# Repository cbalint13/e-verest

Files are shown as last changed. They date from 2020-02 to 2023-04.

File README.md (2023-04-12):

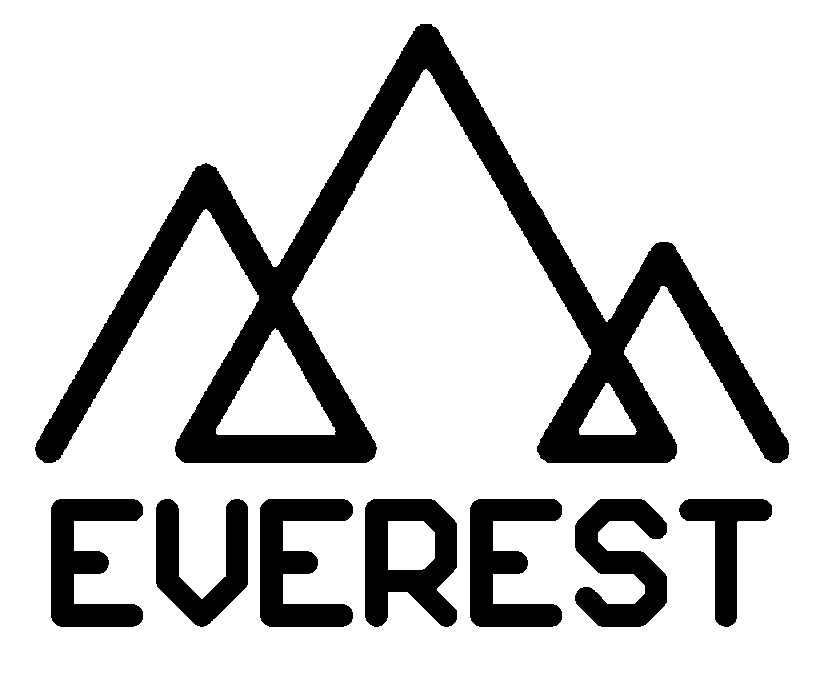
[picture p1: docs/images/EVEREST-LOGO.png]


**e**-**Ve**rsatile **Re**search **St**ick for peoples

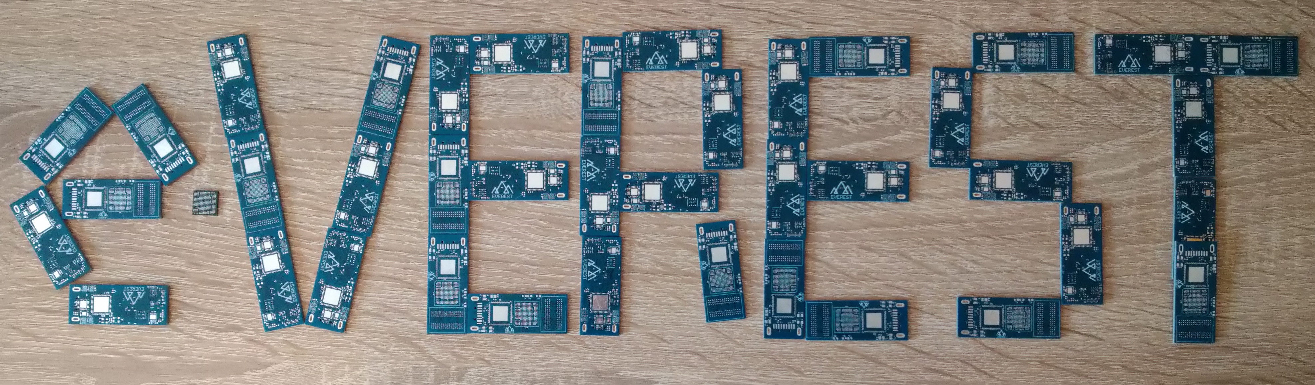
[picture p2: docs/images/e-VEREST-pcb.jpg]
PCB

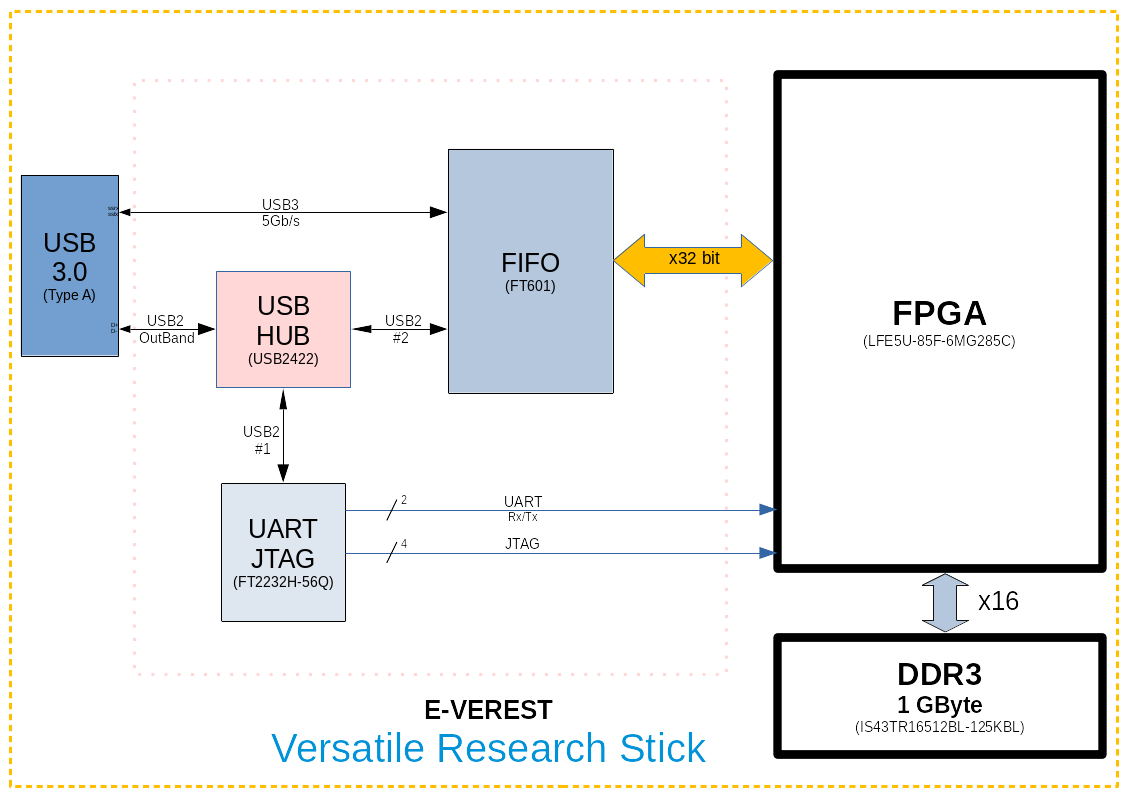
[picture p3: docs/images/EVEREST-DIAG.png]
DIAG


## Description

  With the rising of high quality opensource tools for FPGAs new opportunities are emerging to discover and build better digital architectures.
  This stick is intended as lowest cost tool for anyone who desire to explore & research the world of modern digital systems.
  It can be used to develop, test and benchmark fairly large digital designs, straight using a complete opensource toolchain end to end.

  It can close the gap between emerging trend of high level generated systems (automatic reinforced exploration of arhitectures) and the lack of end to end toolchain harvesting a real FPGA for final feedback.

  Let Here Be Dragons !

## Specs:

* Small size **16x40mm** usb stick
* Generous **85k LUT** **FPGA** logic space
* Holds **1Gbyte DDR3** memory with **x16** wide access
* USB3 **5Gbps/s** data access over **x32** wide independent FIFO
* USB2 outband (same usb port) permanent **JTAG** and **UART** independent access
* Full opensource HDL flow usig [YoSYS](https://github.com/YosysHQ) suite

Can be used in any USB port right from the tips of fingers, no cables, no wires but full control.

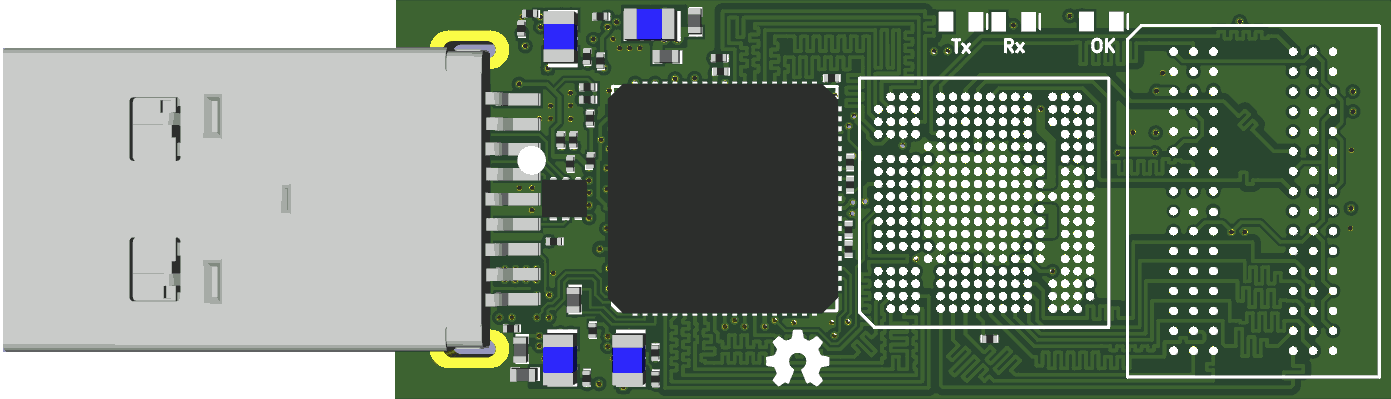
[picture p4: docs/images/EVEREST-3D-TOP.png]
OVERVIEW-TOP

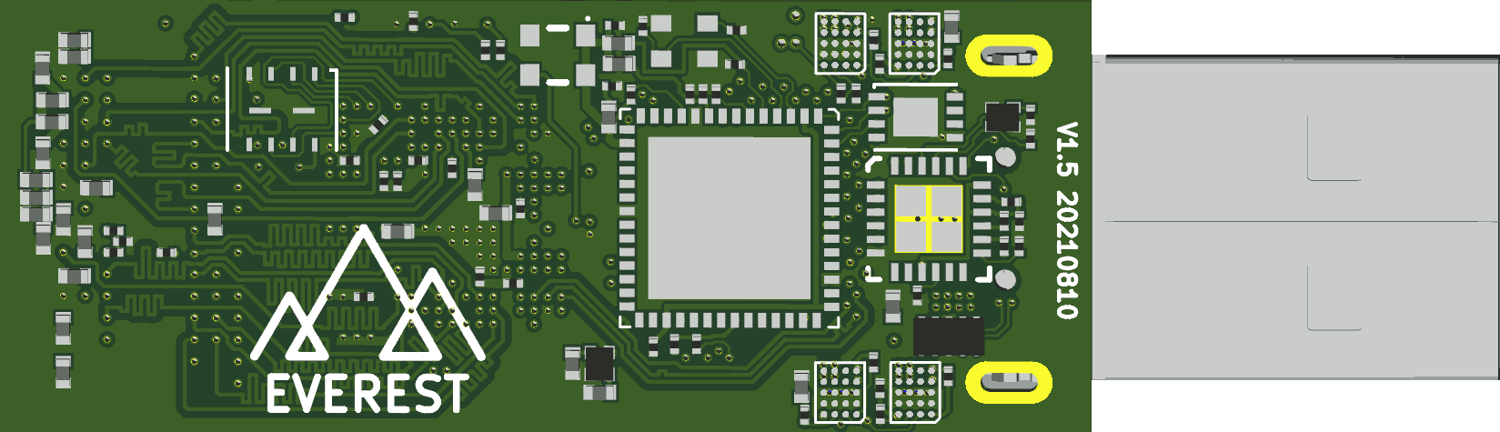
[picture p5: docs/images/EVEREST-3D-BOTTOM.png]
OVERVIEW-BOTTOM


## Progress:
* ```23-Apr-2020``` A batch of 50 PCB arrived. Thank you [WellPCB PTY LTD](https://www.wellpcb.com) !
* ```20-Dec-2020``` Second iteraton of PCB has been done, schematics and pcb design are updated.
* ```20-Jan-2021``` Announcing [OLIMP](https://github.com/cbalint13/OLIMP) having e-VEREST as demo board.
* ```17-Aug-2021``` Third iteration of PCB has been done, design is updated.
* ```10-May-2022``` Due to severe global shortage ~~crowd source~~ batches aren't possible until >2023.

```
Booting..
Press ENTER to continue..

     __     _______ ____  _____ ____ _____
   __\ \   / | ____|  _ \| ____/ ___|_   _|
  / _ \ \ / /|  _| | |_) |  _| \___ \ | |
 |  __/\ V / | |___|  _ <| |___ ___) || |
  \___| \_/  |_____|_| \_|_____|____/ |_|

Total BRAM memory: 32 KiB

Select an action:

   [e] Echo UART

Command>
```

See [utils](/utils) for board peripherial tests and [i/o mappings (lpf file)](https://github.com/cbalint13/e-verest/blob/master/utils/test-firmware/brd/everest.lpf).

## Project files
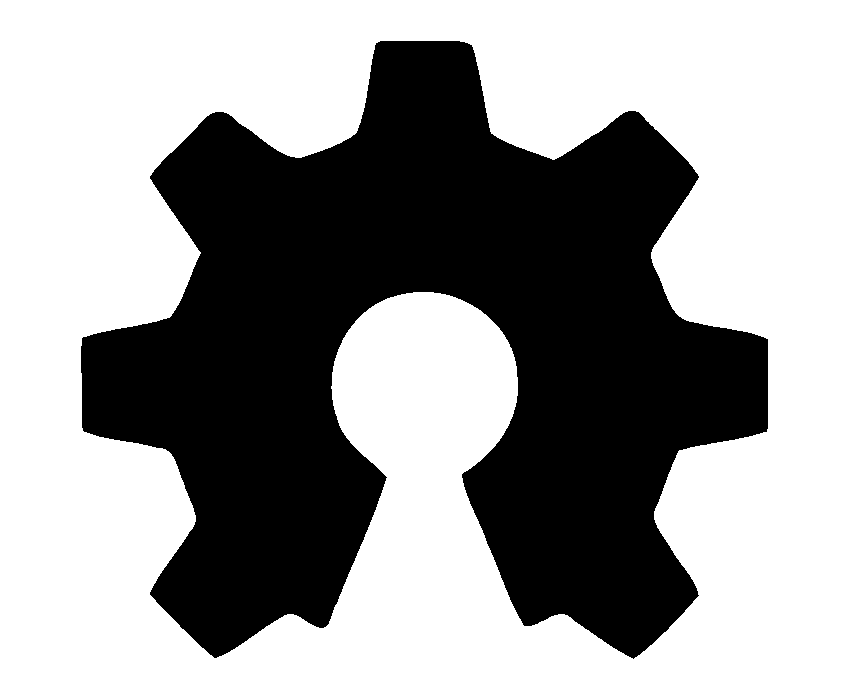
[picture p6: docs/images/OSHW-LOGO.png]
* Open Source Hardware 
* Check [schematic](hardware/e-VEREST-v1_5.pdf) available as quick readable document.
* See the [design files](hardware) available for Altium ®, CircuitMaker ®, KiCAD and Gerber format.
* There is also an CircuitMaker ® [online version](https://circuitmaker.com/Projects/Details/Cristian-Balint/e-VEREST) available.
* Software tools for managing the stick and examples coming soon (WiP)
* There are plans for making batch of units via CrowdSupply campains (WiP).

## PCB views

| Layer | Polygons Description |Image  |
| --- | --- |---|
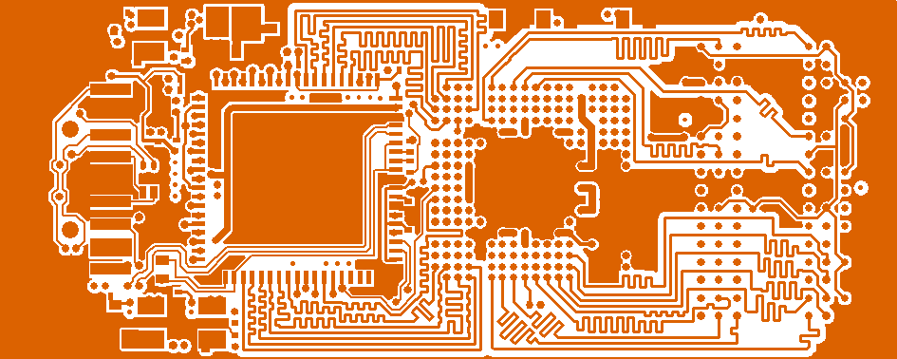
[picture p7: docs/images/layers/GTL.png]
Top Layer
| Top | Signal Layer | |
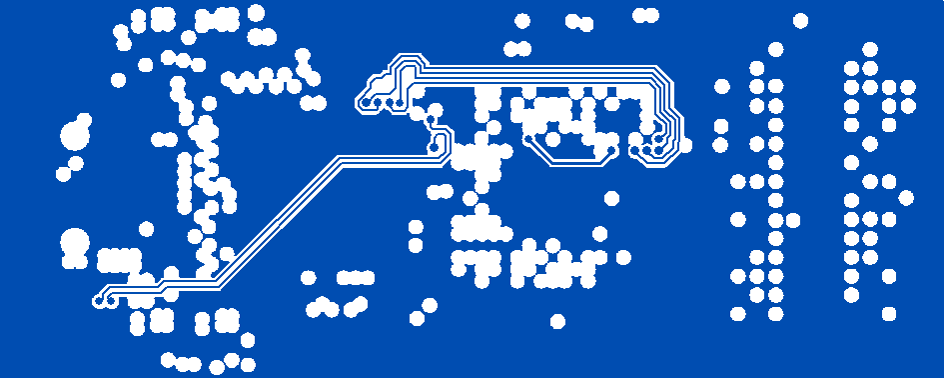
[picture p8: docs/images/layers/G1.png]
Inner Layer 1
| Inner 1 | GND Plane | |
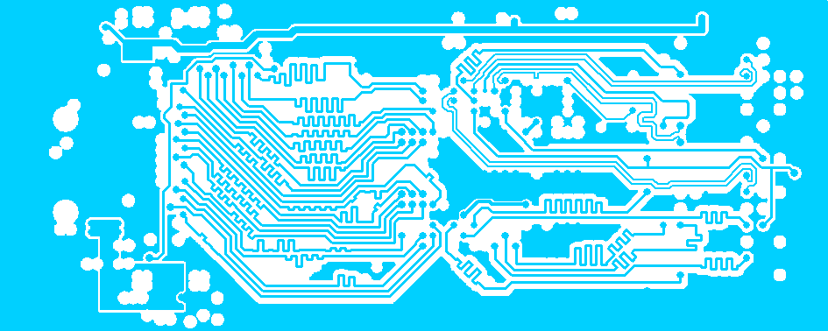
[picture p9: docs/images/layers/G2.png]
Inner Layer 2
| Inner 2 | Signal Layer | |
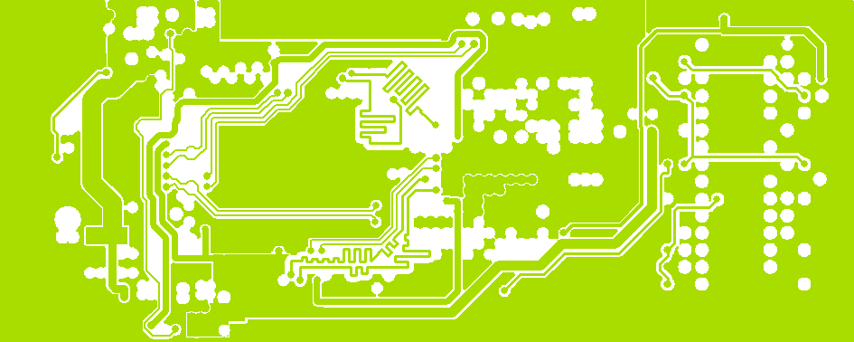
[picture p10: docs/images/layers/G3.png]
Inner Layer 3 Polygon
| Inner 3 | Power Plane | |
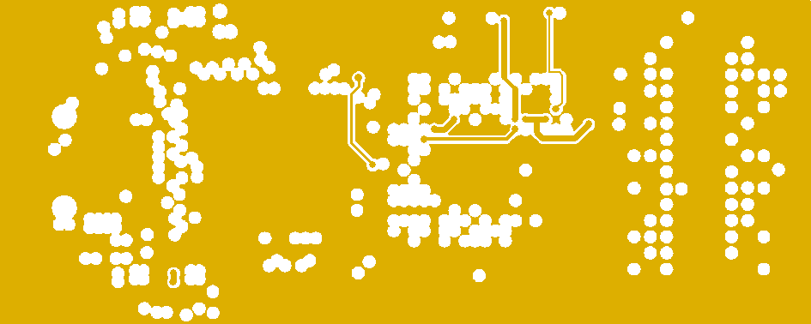
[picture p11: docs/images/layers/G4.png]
Inner Layer 4 Polygons
| Inner 4 | GND Plane | |
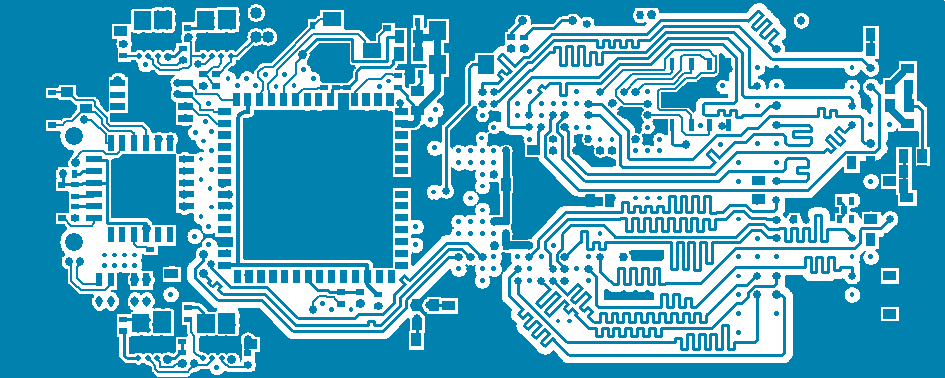
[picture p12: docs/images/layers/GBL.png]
Bottom Layer Polygon
| Bottom |  Signal Layer | |

## Credits

* Communities around [yosys](https://github.com/YosysHQ/yosys) / [nextpnr](https://github.com/YosysHQ/nextpnr)
* The [OrangeCrab](https://github.com/orangecrab-fpga/orangecrab-hardware) board design by Greg Davill

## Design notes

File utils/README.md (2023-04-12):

## USB

Two USB devices with 3 communication channels:
  * *FT2232* as high-speed with:
      - **JTAG** (port A) connected with FPGA
      - **UART** (port B) via /dev/ttyUSB1 to FPGA
  * *FT601* as super-speed x32 bit **FIFO** with the FPGA

```
$ lsusb
Bus 002 Device 002: ID 0403:601f Future Technology Devices International, Ltd FT601 32-bit FIFO IC
Bus 001 Device 012: ID 0403:6010 Future Technology Devices International, Ltd FT2232C/D/H Dual UART/FIFO IC

$ dmesg
[   50.046996] usb 1-6: new high-speed USB device number 7 using xhci_hcd
[   50.173128] usb 1-6: New USB device found, idVendor=0424, idProduct=2422, bcdDevice= 0.a0
[   50.173143] usb 1-6: New USB device strings: Mfr=0, Product=0, SerialNumber=0
[   50.175616] hub 1-6:1.0: USB hub found
[   50.175662] hub 1-6:1.0: 2 ports detected
[   50.462999] usb 1-6.1: new high-speed USB device number 8 using xhci_hcd
[   50.556126] usb 1-6.1: New USB device found, idVendor=0403, idProduct=6010, bcdDevice= 7.00
[   50.556141] usb 1-6.1: New USB device strings: Mfr=1, Product=2, SerialNumber=3
[   50.556148] usb 1-6.1: Product: USB <-> Serial Converter
[   50.556154] usb 1-6.1: Manufacturer: FTDI
[   50.556158] usb 1-6.1: SerialNumber: V1.4_20210810
[   50.642878] usbcore: registered new interface driver ftdi_sio
[   50.642901] usbserial: USB Serial support registered for FTDI USB Serial Device
[   50.642976] ftdi_sio 1-6.1:1.0: FTDI USB Serial Device converter detected
[   50.643013] usb 1-6.1: Detected FT2232H
[   50.643156] usb 1-6.1: FTDI USB Serial Device converter now attached to ttyUSB0
[   50.643199] ftdi_sio 1-6.1:1.1: FTDI USB Serial Device converter detected
[   50.643224] usb 1-6.1: Detected FT2232H
[   50.643328] usb 1-6.1: FTDI USB Serial Device converter now attached to ttyUSB1
```

## JTAG

```
$ openFPGALoader --scan-usb
found 9 USB device
Bus device vid:pid       probe type      manufacturer serial               product
001 008    0x0403:0x6010 FTDI2232        FTDI         V1.4_20210810        USB <-> Serial Converter

$ openFPGALoader -c ft2232 --ftdi-channel 0 --detect
Jtag frequency : requested 6.00MHz   -> real 6.00MHz
index 0:
    idcode 0x1113043
    manufacturer lattice
    family ECP5
    model  LFE5UM-85
    irlength 8
```

## Test firmware

```
$ openFPGALoader -c ft2232 --ftdi-channel 0 --verbose-level 9 everest.bit
Jtag frequency : requested 6.00MHz   -> real 6.00MHz
Raw IDCODE:
- 0 -> 0x41113043
- 1 -> 0xffffffff
- 2 -> 0xffffffff
- 3 -> 0xffffffff
- 4 -> 0xffffffff
found 1 devices
index 0:
    idcode 0x1113043
    manufacturer lattice
    family ECP5
    model  LFE5UM-85
    irlength 8
File type : bit
Open file: DONE
Parse file: DONE
bitstream header infos
Part: LFE5U-85F-6CSFBGA285
idcode: 41113043
IDCode : 41113043
displayReadReg
    Config Target Selection : 0
    Done Flag
    Std PreAmble
    No err
Enable configuration: DONE
SRAM erase: DONE
Loading: [==================================================] 100.00%
Done
userCode: 00000000
Disable configuration: DONE
displayReadReg
    Config Target Selection : 0
    Done Flag
    Std PreAmble
    No err
```

## SPI flash

SPI is accessible via JTAG with [ecpprog](https://github.com/gregdavill/ecpprog) by Greg Davill.

```
$ ./ecpprog everest.bit
init..
IDCODE: 0x41113043 (LFE5U-85)
ECP5 Status Register: 0x00200100
reset..
flash ID: 0xC8 0x40 0x16
file size: 1964814
erase 64kB sector at 0x000000..
erase 64kB sector at 0x010000..
erase 64kB sector at 0x020000..
erase 64kB sector at 0x030000..
erase 64kB sector at 0x040000..
erase 64kB sector at 0x050000..
erase 64kB sector at 0x060000..
erase 64kB sector at 0x070000..
erase 64kB sector at 0x080000..
erase 64kB sector at 0x090000..
erase 64kB sector at 0x0A0000..
erase 64kB sector at 0x0B0000..
erase 64kB sector at 0x0C0000..
erase 64kB sector at 0x0D0000..
erase 64kB sector at 0x0E0000..
erase 64kB sector at 0x0F0000..
erase 64kB sector at 0x100000..
erase 64kB sector at 0x110000..
erase 64kB sector at 0x120000..
erase 64kB sector at 0x130000..
erase 64kB sector at 0x140000..
erase 64kB sector at 0x150000..
erase 64kB sector at 0x160000..
erase 64kB sector at 0x170000..
erase 64kB sector at 0x180000..
erase 64kB sector at 0x190000..
erase 64kB sector at 0x1A0000..
erase 64kB sector at 0x1B0000..
erase 64kB sector at 0x1C0000..
erase 64kB sector at 0x1D0000..
programming..  1964814/1964814
verify..       1964814/1964814  VERIFY OK
Bye.
```

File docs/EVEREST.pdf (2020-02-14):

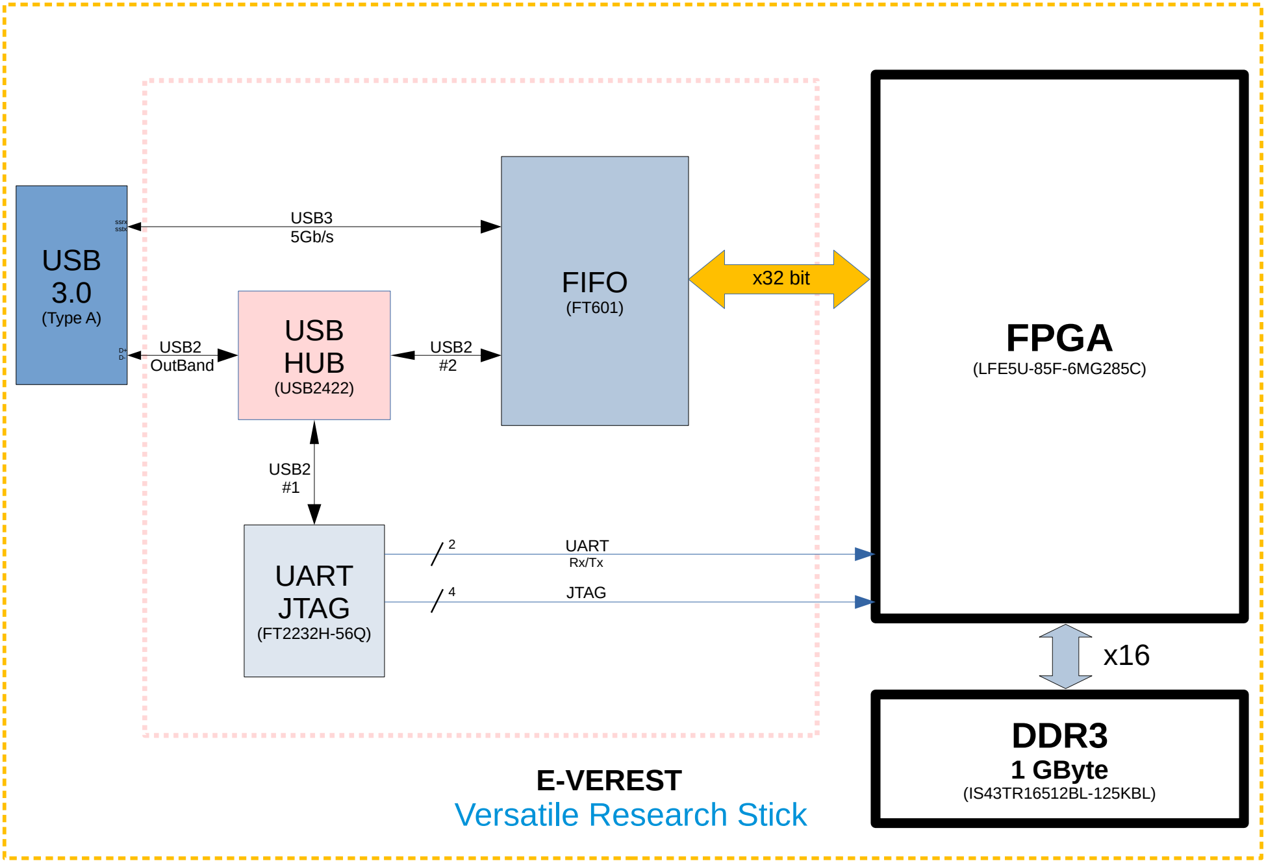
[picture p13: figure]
USB 3.0; (Type A); USB; HUB; (USB2422); FIFO; FPGA; (LFE5U-85F-6MG285C); UART JTAG; USB3 5Gb/s; USB2 OutBand; USB2 #1; UART Rx/Tx; JTAG; USB2 #2; x32 bit; ssrx sstx; E-VEREST Versatile Research Stick; DDR3 1 GByte; (IS43TR16512BL-125KBL)

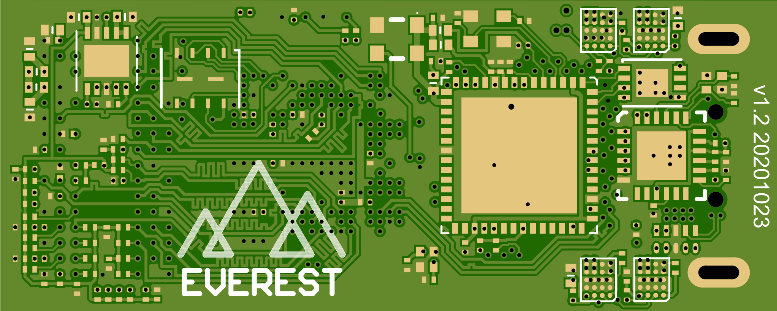
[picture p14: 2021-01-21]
docs/images/EVEREST-PCB-BOTTOM.png

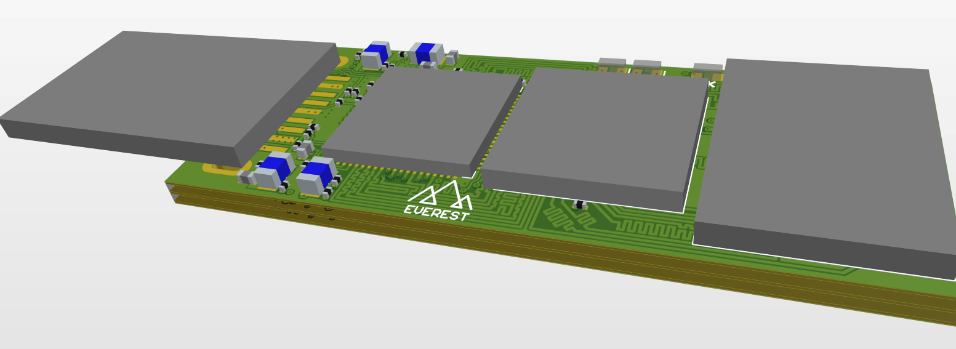
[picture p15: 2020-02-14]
docs/images/EVEREST-3D.png

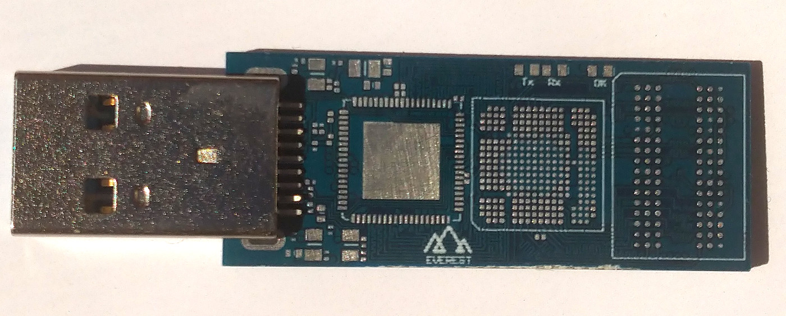
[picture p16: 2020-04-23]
docs/images/e-VEREST-single.jpg

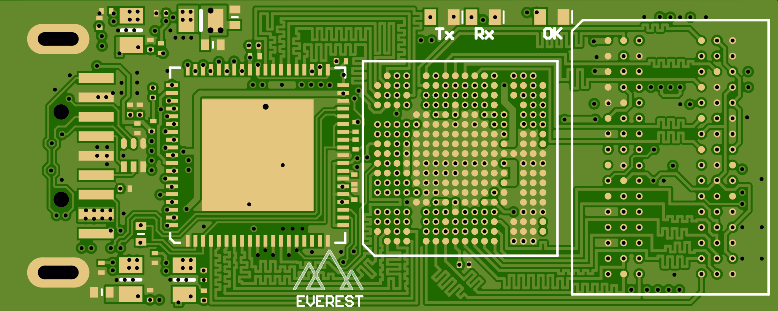
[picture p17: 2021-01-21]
docs/images/EVEREST-PCB-TOP.png

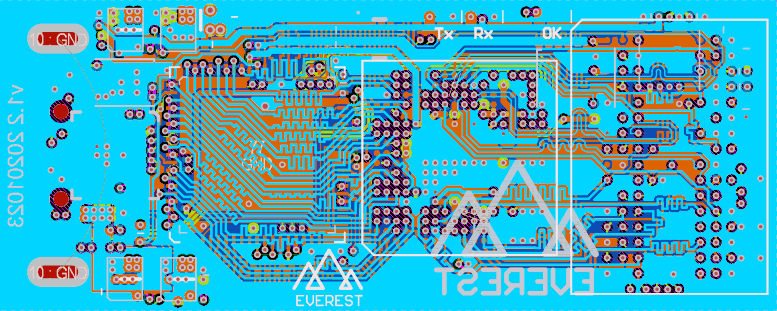
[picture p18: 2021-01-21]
docs/images/EVEREST-PCB-MIDDLE.png

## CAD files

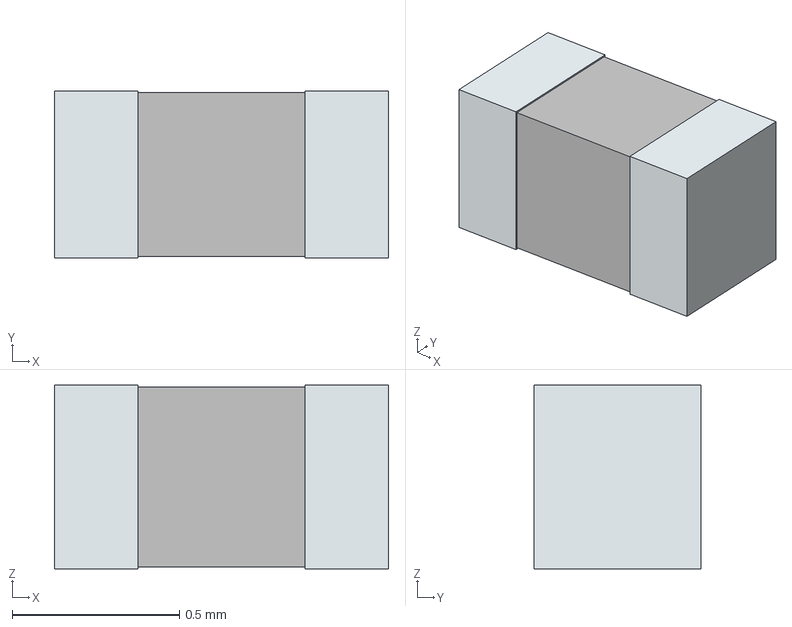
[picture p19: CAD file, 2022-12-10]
hardware/everest_v1.5/kicad/e-verest/3d-models/BLM15AX601SN1D.stp
1.00 x 0.5 x 0.55 mm
term1
term2

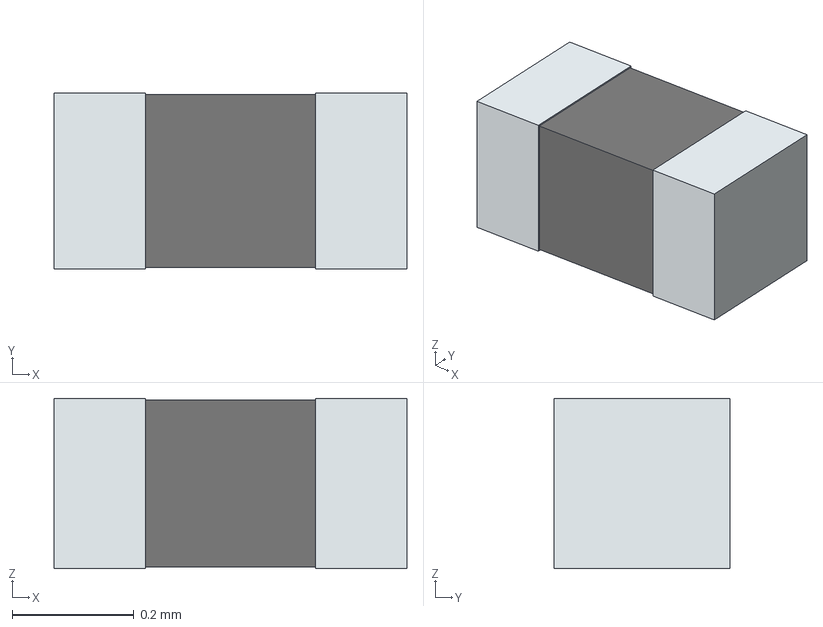
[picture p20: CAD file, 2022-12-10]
hardware/everest_v1.5/kicad/e-verest/3d-models/CPF0201D100RE1.stp
0.58 x 0.29 x 0.28 mm
term1
term2

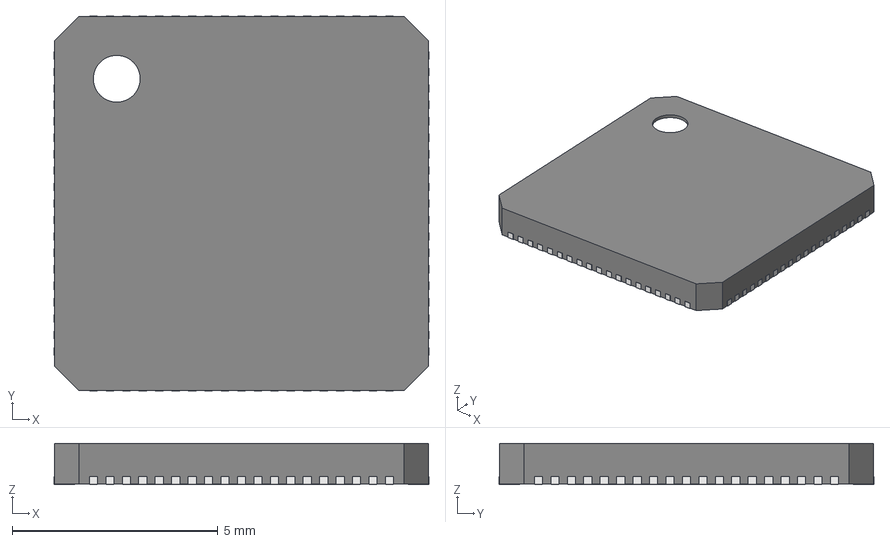
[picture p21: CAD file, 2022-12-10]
hardware/everest_v1.5/kicad/e-verest/3d-models/FT601Q_1.step
9.12 x 9.12 x 1.00 mm
Thermal_Shape

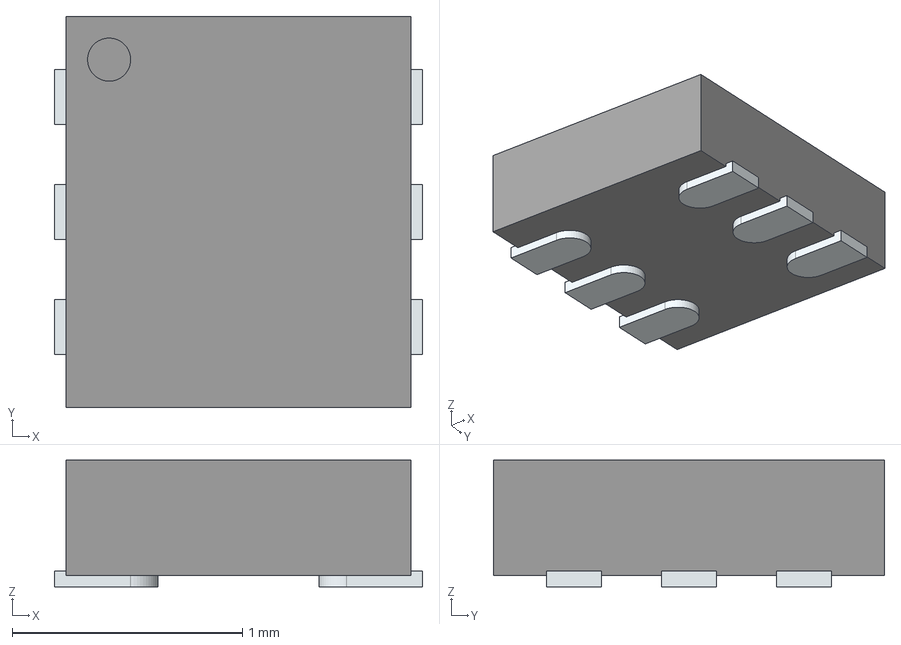
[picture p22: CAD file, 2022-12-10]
hardware/everest_v1.5/kicad/e-verest/3d-models/ECMF02-2AMX6.stp
1.60 x 1.70 x 0.55 mm
PinsArrayLR

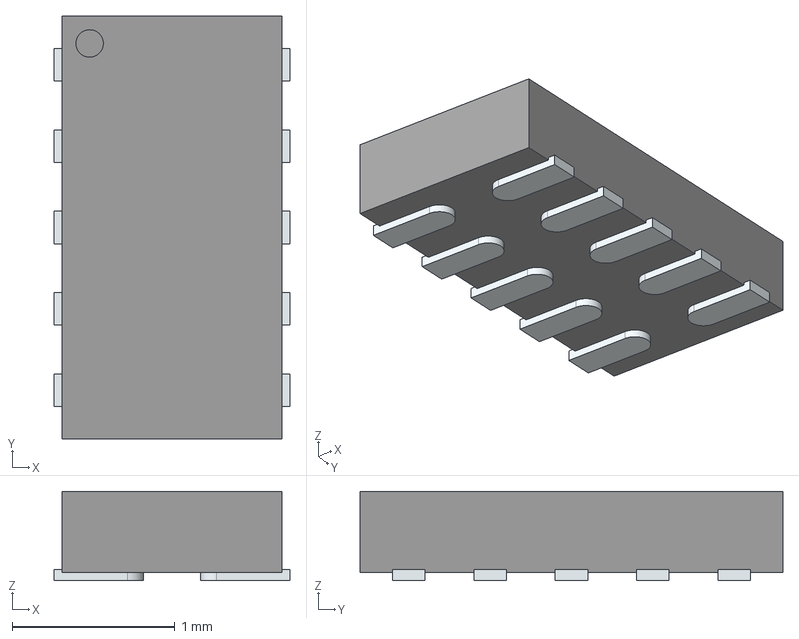
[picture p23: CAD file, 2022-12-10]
hardware/everest_v1.5/kicad/e-verest/3d-models/ECMF04-4HSWM10.stp
1.45 x 2.60 x 0.55 mm
PinsArrayLR

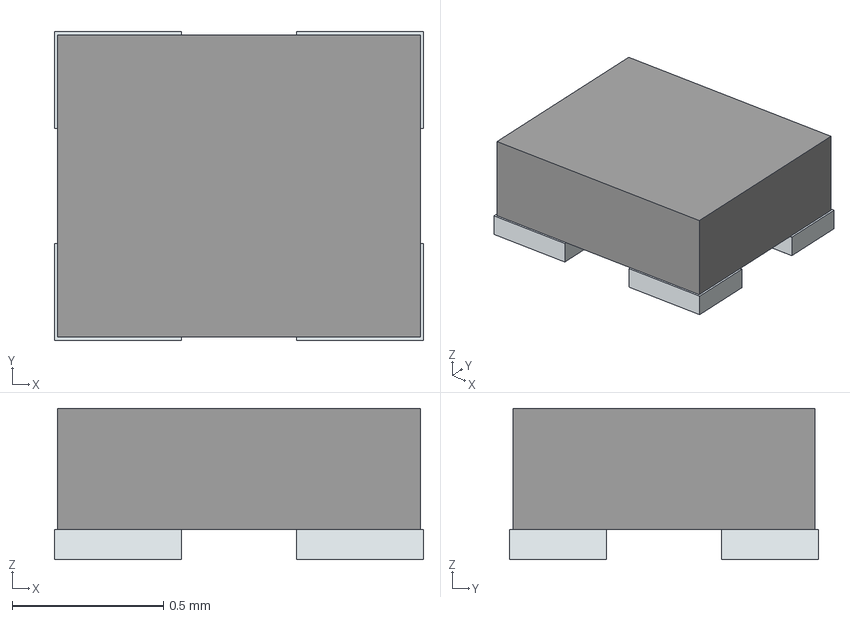
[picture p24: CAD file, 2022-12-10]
hardware/everest_v1.5/kicad/e-verest/3d-models/ABM13W-52.0000MHZ-5-B2G-T5.stp
1.22 x 1.02 x 0.5 mm
('pin',_'1')
('pin',_'2')
('pin',_'3')
('pin',_'4')

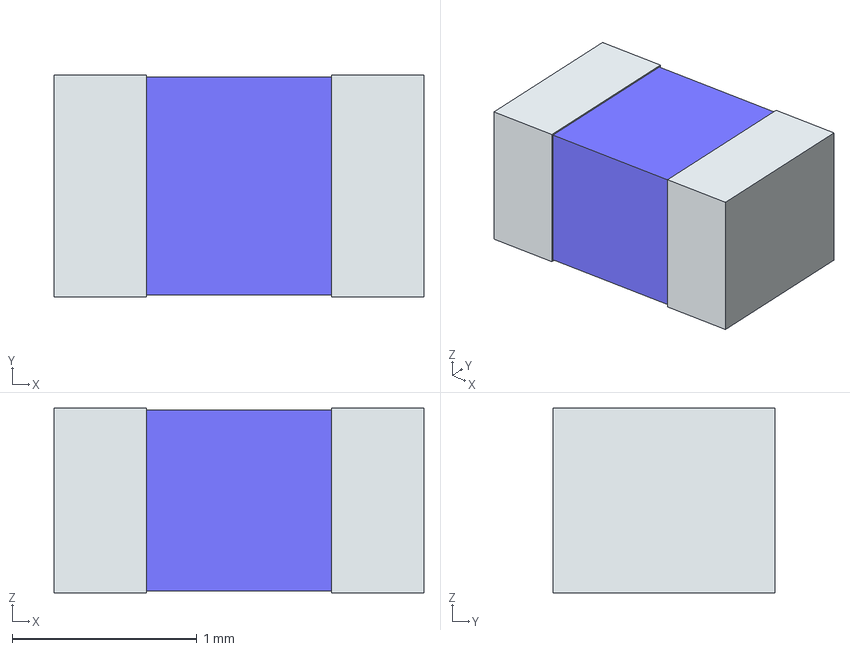
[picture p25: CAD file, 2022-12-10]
hardware/everest_v1.5/kicad/e-verest/3d-models/74479775147.stp
2.00 x 1.20 x 1.00 mm
term1
term2

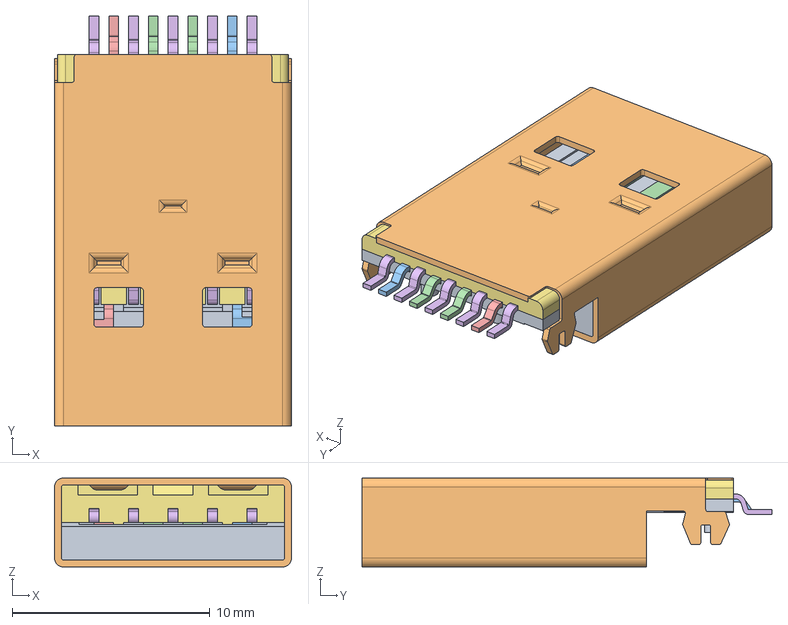
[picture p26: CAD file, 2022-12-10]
hardware/everest_v1.5/kicad/e-verest/3d-models/692112030100.stp
12.0 x 20.8 x 4.50 mm

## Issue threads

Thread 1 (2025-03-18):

Version Number Discrepancy

meiniKi, 2025-03-18:
The latest Gerber files mention "V1.4 20210810," whereas the latest PCB in KiCad mentions the identical date but a more recent version, "V1.5 20210810". Are these boards identical?

cbalint13, 2025-03-18:
Hi @meiniKi ,

Yes they are identical,  20210810 is the date of last iteration (manufactured), the project was incremented in the idea for possible next iterations but wasn't the case.

meiniKi, 2025-03-19:
Great! Thank you for your fast reply 🙂

Closed 2025-03-19.

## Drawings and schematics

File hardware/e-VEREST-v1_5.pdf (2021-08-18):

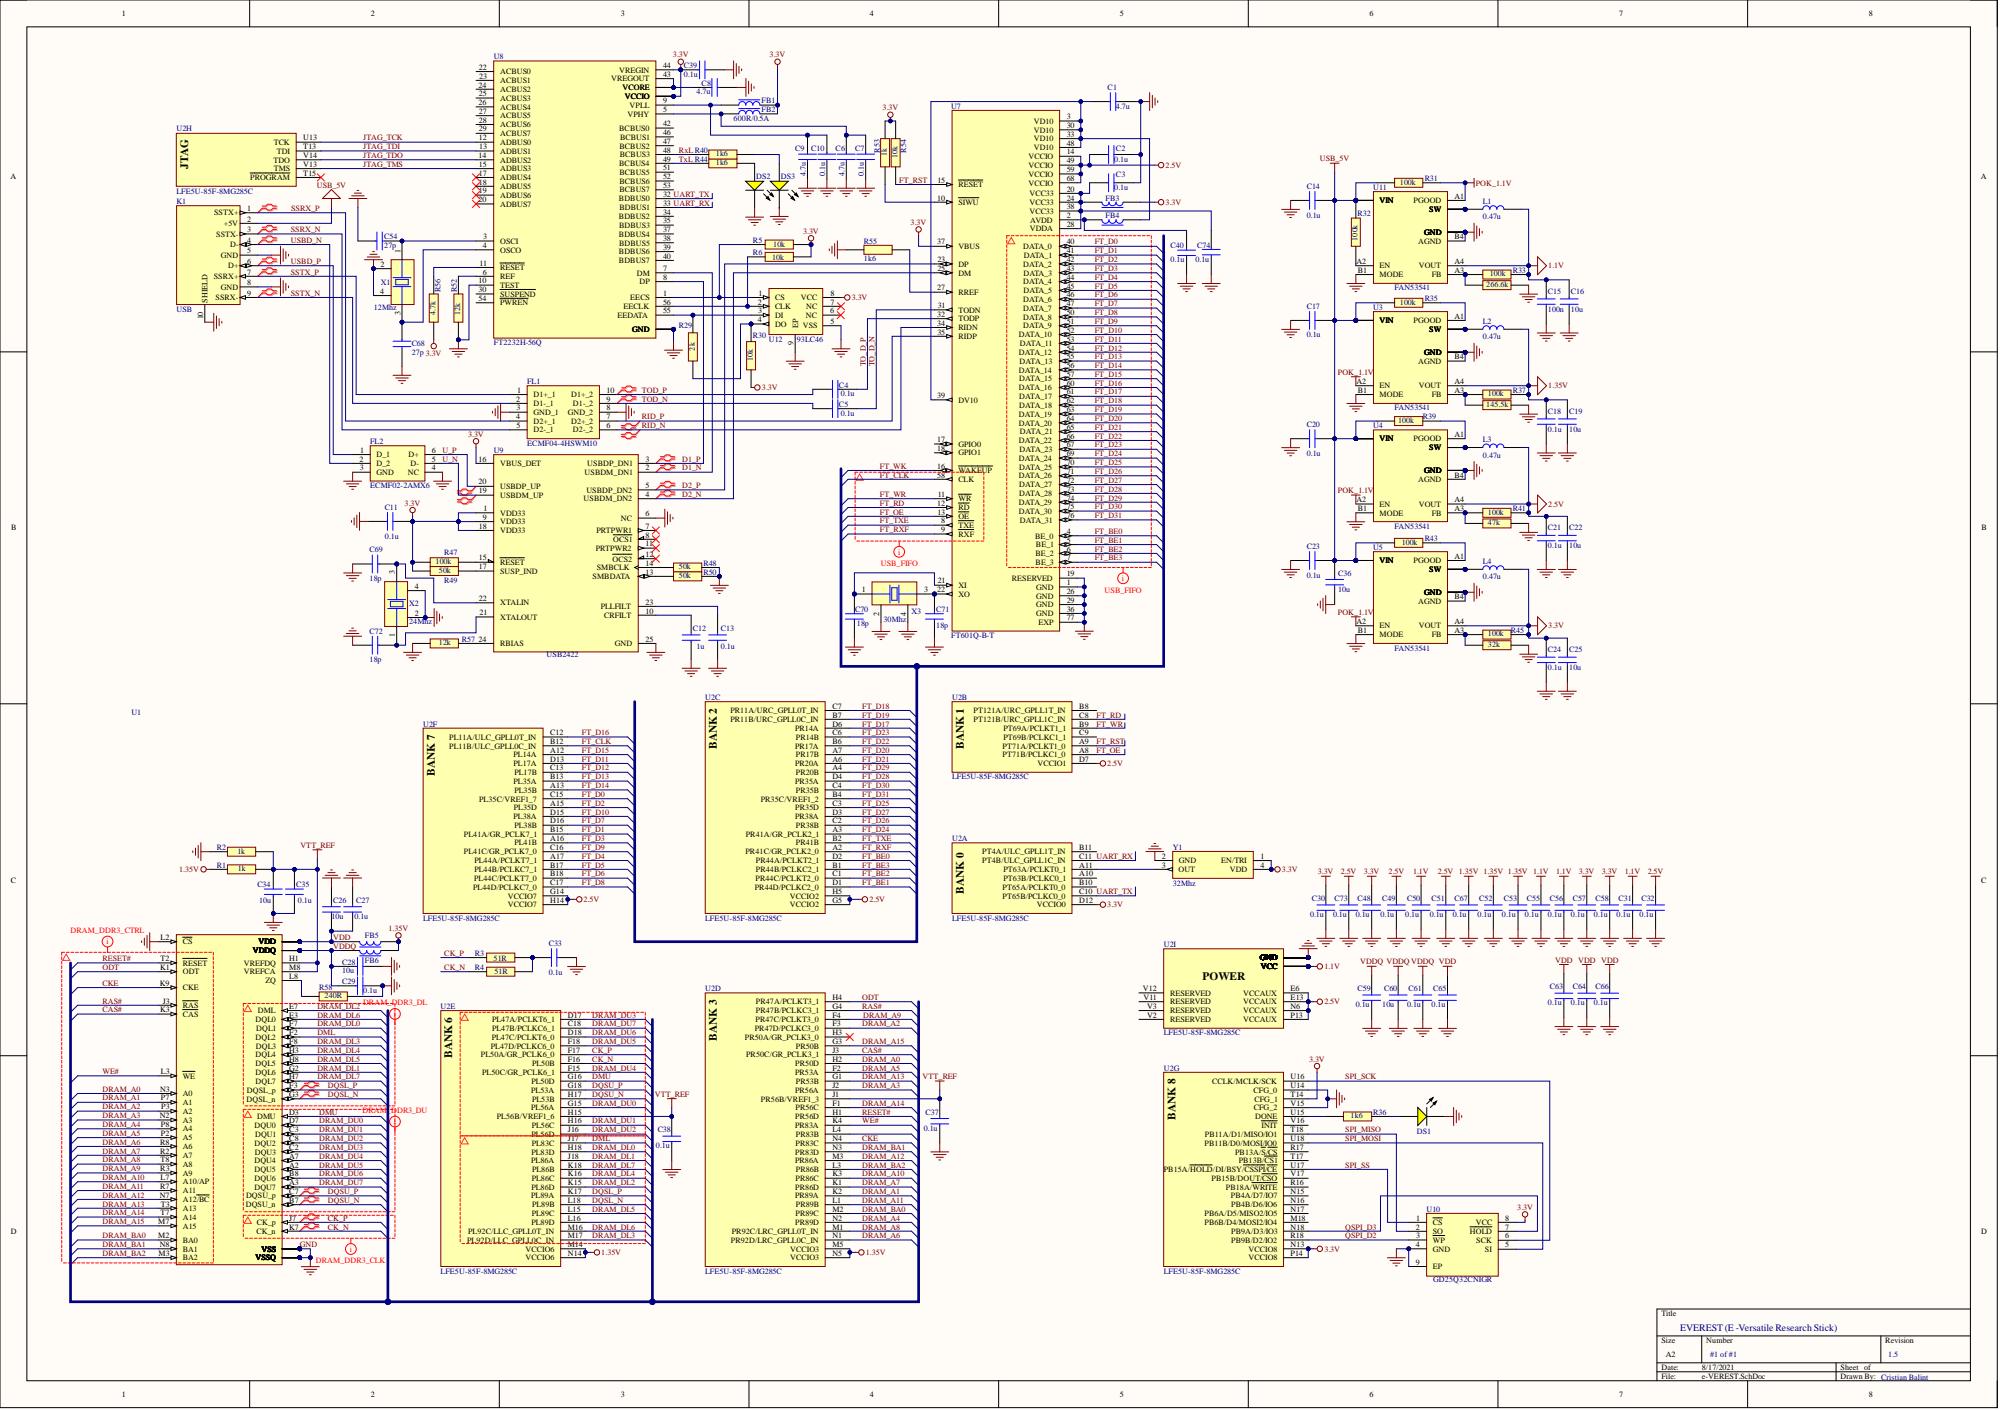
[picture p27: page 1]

RID_P | | 0.1u

D2-_1 5 | RID_N | FT_D21

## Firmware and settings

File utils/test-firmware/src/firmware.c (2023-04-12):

/*
 *  PicoSoC - A simple example SoC using PicoRV32
 *
 *  Copyright (C) 2017  Clifford Wolf <clifford@clifford.at>
 *                2023  Balint Cristian <cristian dot balint at gmail dot com>
 *
 *  Permission to use, copy, modify, and/or distribute this software for any
 *  purpose with or without fee is hereby granted, provided that the above
 *  copyright notice and this permission notice appear in all copies.
 *
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
 */

#include <stdint.h>
#include <stdbool.h>


#define F_CPU     50000000 // Hz
#define BAUD_RATE   115200 // bit/s
#define MEM_TOTAL   0x8000

#define reg_uart_clkdiv (*(volatile uint32_t*)0x02000004)
#define reg_uart_data (*(volatile uint32_t*)0x02000008)

// --------------------------------------------------------

int putchar(int c) {
  c &= 0xFF;
  if (c == '\n') putchar('\r');
  reg_uart_data = c;
}

void print(const char *p) {
  while (*p) putchar(*(p++));
}

void print_hex(uint32_t v, int digits) {
  for (int i = 7; i >= 0; i--) {
    char c = "0123456789abcdef"[(v >> (4*i)) & 15];
    if (c == '0' && i >= digits) continue;
    putchar(c);
    digits = i;
  }
}

void print_dec(uint32_t v) {
  if (v >= 1000) {
    print(">=1000");
    return;
  }

  if      (v >= 900) { putchar('9'); v -= 900; }
  else if (v >= 800) { putchar('8'); v -= 800; }
  else if (v >= 700) { putchar('7'); v -= 700; }
  else if (v >= 600) { putchar('6'); v -= 600; }
  else if (v >= 500) { putchar('5'); v -= 500; }
  else if (v >= 400) { putchar('4'); v -= 400; }
  else if (v >= 300) { putchar('3'); v -= 300; }
  else if (v >= 200) { putchar('2'); v -= 200; }
  else if (v >= 100) { putchar('1'); v -= 100; }

  if      (v >= 90) { putchar('9'); v -= 90; }
  else if (v >= 80) { putchar('8'); v -= 80; }
  else if (v >= 70) { putchar('7'); v -= 70; }
  else if (v >= 60) { putchar('6'); v -= 60; }
  else if (v >= 50) { putchar('5'); v -= 50; }
  else if (v >= 40) { putchar('4'); v -= 40; }
  else if (v >= 30) { putchar('3'); v -= 30; }
  else if (v >= 20) { putchar('2'); v -= 20; }
  else if (v >= 10) { putchar('1'); v -= 10; }

  if      (v >= 9) { putchar('9'); v -= 9; }
  else if (v >= 8) { putchar('8'); v -= 8; }
  else if (v >= 7) { putchar('7'); v -= 7; }
  else if (v >= 6) { putchar('6'); v -= 6; }
  else if (v >= 5) { putchar('5'); v -= 5; }
  else if (v >= 4) { putchar('4'); v -= 4; }
  else if (v >= 3) { putchar('3'); v -= 3; }
  else if (v >= 2) { putchar('2'); v -= 2; }
  else if (v >= 1) { putchar('1'); v -= 1; }
  else putchar('0');
}

char getchar_prompt(char *prompt) {

  if (prompt) {
    print(prompt);
  }

  int32_t c = -1;

  while (c == -1) {
    c = reg_uart_data;
  }

  return c & 0xFF;
}

char getchar() {
  return getchar_prompt(0);
}

// --------------------------------------------------------

void cmd_echo() {
  print("Return to menu by sending '!'\n\n");
  char c;
  while ((c = getchar()) != '!') putchar(c);
}

// --------------------------------------------------------

void main() {
  int c = 0;
  while (c < 10000) { c++; }
  c = 0;

  reg_uart_clkdiv = F_CPU/BAUD_RATE;
  print("Booting..\n");

  //print("Press ENTER to continue..\n");
  // while (getchar_prompt(0) != '\r') { /* wait */ }

  print("\n");

  print("     __     _______ ____  _____ ____ _____\n");
  print("   __\\ \\   / | ____|  _ \\| ____/ ___|_   _|\n");
  print("  / _ \\ \\ / /|  _| | |_) |  _| \\___ \\ | |\n");
  print(" |  __/\\ V / | |___|  _ <| |___ ___) || |\n");
  print("  \\___| \\_/  |_____|_| \\_|_____|____/ |_|\n");

  print("\n");

  print("Total memory: ");
  print_dec(MEM_TOTAL / 1024);
  print(" KiB\n");
  print("\n");

  //cmd_memtest(); // test overwrites bss and data memory
  print("\n");

  while (1)
  {
    print("\n");

    print("Select an action:\n");
    print("\n");
    print("   [e] Echo UART\n");
    print("\n");

    for (int rep = 10; rep > 0; rep--)
    {
      print("Command> ");
      char cmd = getchar();
      if (cmd > 32 && cmd < 127) putchar(cmd);
      print("\n");

      switch (cmd)
      {
      case 'e':
        cmd_echo();
        break;
      default:
        continue;
      }

      break;
    }
  }
}

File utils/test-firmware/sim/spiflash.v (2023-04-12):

/*
 *
 *  Copyright (C) 2017  Clifford Wolf <clifford@clifford.at>
 *                2021  Cristian Balint <cristian dot balint at gmail dot com>
 *
 *  Permission to use, copy, modify, and/or distribute this software for any
 *  purpose with or without fee is hereby granted, provided that the above
 *  copyright notice and this permission notice appear in all copies.
 *
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
 */

`timescale 1 ns / 1 ps

//
// Simple SPI flash simulation model
//
// This model samples io input signals 1ns before the SPI clock edge and
// updates output signals 1ns after the SPI clock edge.
//
// Supported commands:
//    AB, B9, FF, 03, BB, EB, ED
//
// Well written SPI flash data sheets:
//    Cypress S25FL064L http://www.cypress.com/file/316661/download
//    Cypress S25FL128L http://www.cypress.com/file/316171/download
//
// SPI flash used on iCEBreaker board:
//    https://www.winbond.com/resource-files/w25q128jv%20dtr%20revb%2011042016.pdf
//

module spiflash (
    input csb,
    input clk,
    inout io0, // MOSI
    inout io1, // MISO
    inout io2,
    inout io3
);
    localparam verbose = 0;
    localparam integer latency = 7;

    reg [7:0] buffer;
    integer bitcount = 0;
    integer bytecount = 0;
    integer dummycount = 0;

    reg [7:0] spi_cmd;
    reg [7:0] xip_cmd = 0;
    reg [23:0] spi_addr;

    reg [7:0] spi_in;
    reg [7:0] spi_out;
    reg spi_io_vld;

    reg qpi_mode = 0;
    reg powered_up = 0;

    localparam [3:0] mode_spi         = 0;
    localparam [3:0] mode_qpi         = 1;
    localparam [3:0] mode_dspi_rd     = 2;
    localparam [3:0] mode_dspi_wr     = 3;
    localparam [3:0] mode_qspi_rd     = 4;
    localparam [3:0] mode_qspi_wr     = 5;
    localparam [3:0] mode_qspi_ddr_rd = 6;
    localparam [3:0] mode_qspi_ddr_wr = 7;

    reg [3:0] mode = 0;
    reg [3:0] next_mode = 0;

    reg io0_oe = 0;
    reg io1_oe = 0;
    reg io2_oe = 0;
    reg io3_oe = 0;

    reg io0_dout = 0;
    reg io1_dout = 0;
    reg io2_dout = 0;
    reg io3_dout = 0;

    assign #1 io0 = io0_oe ? io0_dout : 1'bz;
    assign #1 io1 = io1_oe ? io1_dout : 1'bz;
    assign #1 io2 = io2_oe ? io2_dout : 1'bz;
    assign #1 io3 = io3_oe ? io3_dout : 1'bz;

    wire io0_delayed;
    wire io1_delayed;
    wire io2_delayed;
    wire io3_delayed;

    assign #1 io0_delayed = io0;
    assign #1 io1_delayed = io1;
    assign #1 io2_delayed = io2;
    assign #1 io3_delayed = io3;

    // 16 MB (128Mb) Flash
    reg [7:0] memory [0:16*1024*1024-1];

    reg [1023:0] firmware_file;
    initial begin
        if (!$value$plusargs("firmware=%s", firmware_file))
            firmware_file = "firmware.hex";
        $readmemh(firmware_file, memory);
    end

    task spi_action;
        begin
            spi_in = buffer;

            if (bytecount == 1) begin
                spi_cmd = buffer;

                if (spi_cmd == 8'h ab)
                    powered_up = 1;

                if (spi_cmd == 8'h b9)
                    powered_up = 0;

                if (spi_cmd == 8'h ff)
                    xip_cmd = 0;

                if (spi_cmd == 8'h 38)
                begin
                    qpi_mode = 1;
                    xip_cmd = 0;
                end

                if (spi_cmd == 8'h 66)
                    xip_cmd = 0;

                if (spi_cmd == 8'h 99)
                begin
                    powered_up = 1;
                    xip_cmd = 0;
                end
            end

            if (powered_up && spi_cmd == 'h 03) begin
                if (bytecount == 2)
                    spi_addr[23:16] = buffer;

                if (bytecount == 3)
                    spi_addr[15:8] = buffer;

                if (bytecount == 4)
                    spi_addr[7:0] = buffer;

                if (bytecount >= 4) begin
                    buffer = memory[spi_addr];
                    spi_addr = spi_addr + 1;
                end
            end

            if (powered_up && spi_cmd == 'h bb) begin
                if (bytecount == 1)
                    mode = mode_dspi_rd;

                if (bytecount == 2)
                    spi_addr[23:16] = buffer;

                if (bytecount == 3)
                    spi_addr[15:8] = buffer;

                if (bytecount == 4)
                    spi_addr[7:0] = buffer;

                if (bytecount == 5) begin
                    xip_cmd = (buffer == 8'h a5) ? spi_cmd : 8'h 00;
                    mode = mode_dspi_wr;
                    dummycount = latency;
                end

                if (bytecount >= 5) begin
                    buffer = memory[spi_addr];
                    spi_addr = spi_addr + 1;
                end
            end

            if (powered_up && spi_cmd == 'h eb) begin
                if (bytecount == 1)
                    mode = mode_qspi_rd;

                if (bytecount == 2)
                    spi_addr[23:16] = buffer;

                if (bytecount == 3)
                    spi_addr[15:8] = buffer;

                if (bytecount == 4)
                    spi_addr[7:0] = buffer;

                if (bytecount == 5) begin
                    xip_cmd = (buffer == 8'h a5) ? spi_cmd : 8'h 00;
                    mode = mode_qspi_wr;
                    dummycount = latency;
                end

                if (bytecount >= 5) begin
                    buffer = memory[spi_addr];
                    spi_addr = spi_addr + 1;
                end
            end

            if (powered_up && spi_cmd == 'h ed) begin
                if (bytecount == 1)
                    next_mode = mode_qspi_ddr_rd;

                if (bytecount == 2)
                    spi_addr[23:16] = buffer;

                if (bytecount == 3)
                    spi_addr[15:8] = buffer;

                if (bytecount == 4)
                    spi_addr[7:0] = buffer;

                if (bytecount == 5) begin
                    xip_cmd = (buffer == 8'h a5) ? spi_cmd : 8'h 00;
                    mode = mode_qspi_ddr_wr;
                    dummycount = latency;
                end

                if (bytecount >= 5) begin
                    buffer = memory[spi_addr];
                    spi_addr = spi_addr + 1;
                end
            end

            spi_out = buffer;
            spi_io_vld = 1;

            if (verbose) begin
                if (bytecount == 1)
                    $write("<SPI-START>");
                $write("<SPI:%02x:%02x>", spi_in, spi_out);
            end

        end
    endtask

    task ddr_rd_edge;
        begin
            buffer = {buffer, io3_delayed, io2_delayed, io1_delayed, io0_delayed};
            bitcount = bitcount + 4;
            if (bitcount == 8) begin
                bitcount = 0;
                bytecount = bytecount + 1;
                spi_action;
            end
        end
    endtask

    task ddr_wr_edge;
        begin
            io0_oe = 1;
            io1_oe = 1;
            io2_oe = 1;
            io3_oe = 1;
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

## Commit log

2020-04-23 Add PCB news.
2020-04-23 Smaller PCB jpg variant.
2021-08-18 Update to v1.5
    [e-VEREST.PcbLib, e-VEREST.PrjPcb, e-VEREST.SchDoc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]
2022-12-10 Add missing 3d-models for the kicad project.
    [692112030100.stp, 74479775147.stp, ABM13W-52.0000MHZ-5-B2G-T5.stp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]
